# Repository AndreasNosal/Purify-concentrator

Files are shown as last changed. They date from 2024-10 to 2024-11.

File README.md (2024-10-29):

# Purify-concentrator
This device is designed to monitor and detect air quality at regular intervals, providing alerts when pollution levels become too high—prompting you to take action, such as opening a window. Ideal for indoor environments like homes, schools, or offices, it operates efficiently with a solar power input ranging from 5 to 16V.

Originally designed for: Young Energy Europe AHK Slowakei 
Link: https://slowakei.ahk.de/de

# License
 - Under GPL-3.0 license

# Use in action


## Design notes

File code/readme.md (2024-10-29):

# Starter-Friendly Electrical Project for DIY Assembly

### Contributors: 
- **Filip Greguš**
- **Andreas Nosál**

### Project:
- **Commissioned by**: Young Energy Europe AHK Slowakei
- **Date**: 29 October 2024
- **License**: [GNU General Public License v3.0](https://www.gnu.org/licenses/gpl-3.0.html)
- **Programming language**: micropython
- **Microcontroller**: ESP32 Wemos D1 mini - WROOM-32

## Hardware Components

1. **ESP32 microcontroller**: Main control unit for executing code and handling inputs/outputs.
2. **BME680 Sensor**: Measures temperature, pressure, humidity, and gas levels.
3. **SSD1306 OLED Display**: Displays real-time data.
4. **Battery and Power Monitoring**: Tracks battery voltage and alerts on low charge.
5. **LEDs and Buzzer**: Provides visual and audio notifications based on sensor data.

---

## Code Explanation and Main Functionalities

- **Sensor Initialization**: Initializes the I2C connection with the BME680 sensor and OLED display.
- **Environmental Data Processing**: Reads temperature, pressure, humidity, and gas data from the sensor and calculates an Indoor Air Quality (IAQ) index.
- **Battery Monitoring**: Reads and computes the battery percentage based on ADC voltage input.
- **LED & Buzzer Notifications**: LED colors indicate air quality levels, while the buzzer sounds when IAQ exceeds safe thresholds.
- **Display Control**: Cycles through different display modes showing temperature, humidity, pressure, and battery status.
- **Data Storage**: Saves IAQ, gas levels, uptime, and other data to RTC memory for persistence after restarts.
- **Data Persistence**: Saves readings to RTC memory for recovery after power loss or restart.
- **Deep Sleep Mode**: Activates deep sleep during idle times to conserve battery.

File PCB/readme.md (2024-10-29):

# Starter-Friendly Electrical Design for DIY Assembly

This project is an electrical design crafted to be accessible for **beginners**. It employs **through-hole components (THD)**, making it easy to assemble with a standard soldering iron. All complex circuitry is integrated into modules that mount directly onto the main PCB, eliminating the need for surface-mount devices (SMD) and simplifying the soldering process.

## Features

- **Overvoltage Protection**: Prevents damage from voltage spikes.
- **Reverse Voltage Protection**: Guards against incorrect polarity connections.
- **Active Buzzer & LED Indicators**: Provides clear audio and visual feedback.
- **Energy-Efficient Components**: Designed to conserve power.
- **Flexible Input Voltage (5-16V)**: Compatible with a range of sources, including solar panels.
- **Microcontroller Reset Button**: Convenient reset for the ESP32 microcontroller.
- **Input Power Options**: Supports both DC barrel jack and PH2 connectors.

## PCB Specifications

- **4-Layer PCB**
- **Dimensions**: 100x100 mm
- **Manufacturing**: Gerber files are available in the `gerber` directory, ready for JLCPCB.

[yee_diagram.pdf](https://github.com/user-attachments/files/17554162/yee_diagram.pdf)


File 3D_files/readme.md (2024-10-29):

# Device Case Instructions

This device case is designed for **standard 3D printers** (FFF/FDM) such as the Prusa MK3S and Ender 3.

### Printing Recommendations
- **Supports**: Minimal supports required.
- **Material**: PLA recommended (eco-friendly, organic plastic).

### Features
- **Protection**: Shields internal components with a professional, sleek design.
- **Indoor Use**: Ideal for home, work, or school environments. **Not recommended** for outdoor use.

### Solar Panel Stands
- **Tool-Free Installation**: Stands for solar panels can be easily inserted or removed without any tools.

### Assembly
To tighten and reinforce the case, you’ll need:
- **4 M3 screws (10mm length)**.

focus_maintainer
a5b3d7db-29c4-4471-a50c-b73762182b38

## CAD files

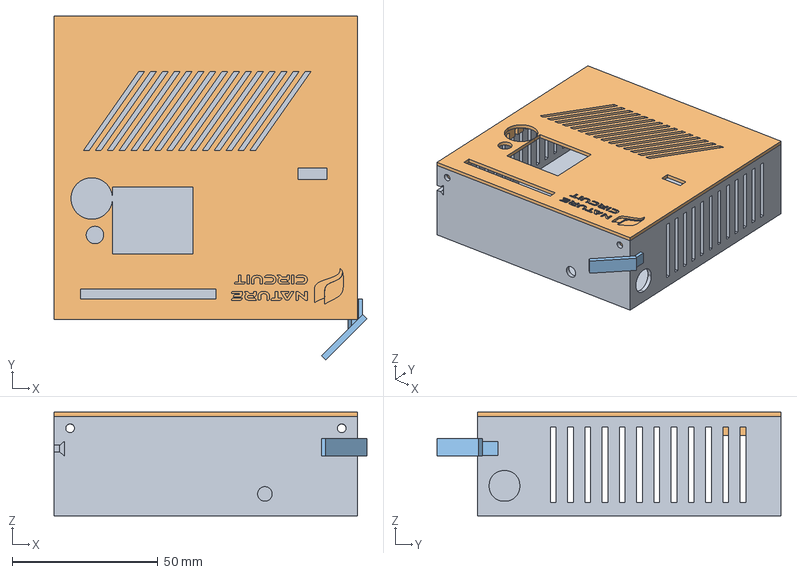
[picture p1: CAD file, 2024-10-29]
3D_files/Focus maintainer v24.step
107.2 x 117.8 x 35.5 mm

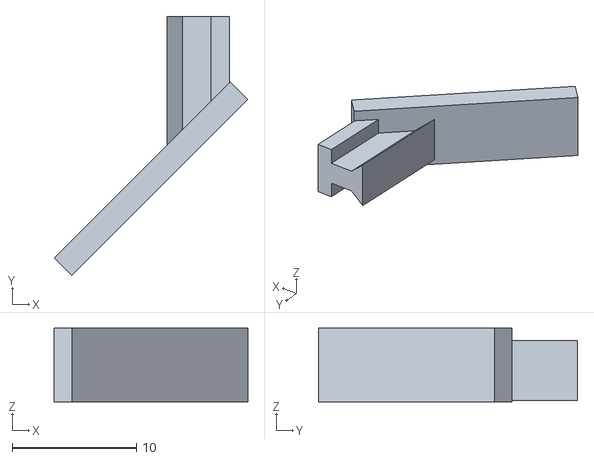
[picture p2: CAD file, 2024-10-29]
3D_files/solar_holder.stl
15.6 x 20.8 x 5.93

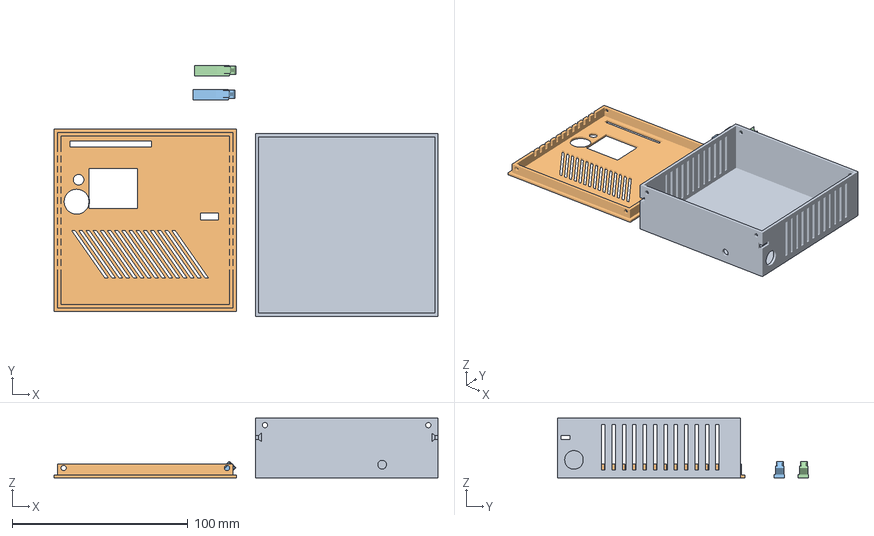
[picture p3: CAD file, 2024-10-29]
3D_files/YEE.3mf
218.6 x 142.7 x 34.0 mm
bottom_box.stl
top_box.stl
solar_holder.stl

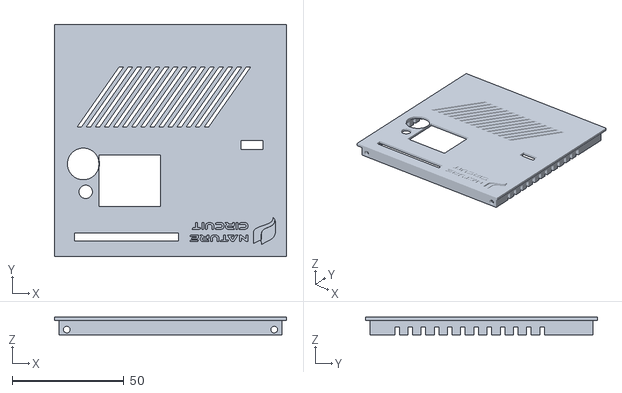
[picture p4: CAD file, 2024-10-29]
3D_files/top_box.stl
104.0 x 104.0 x 8.00

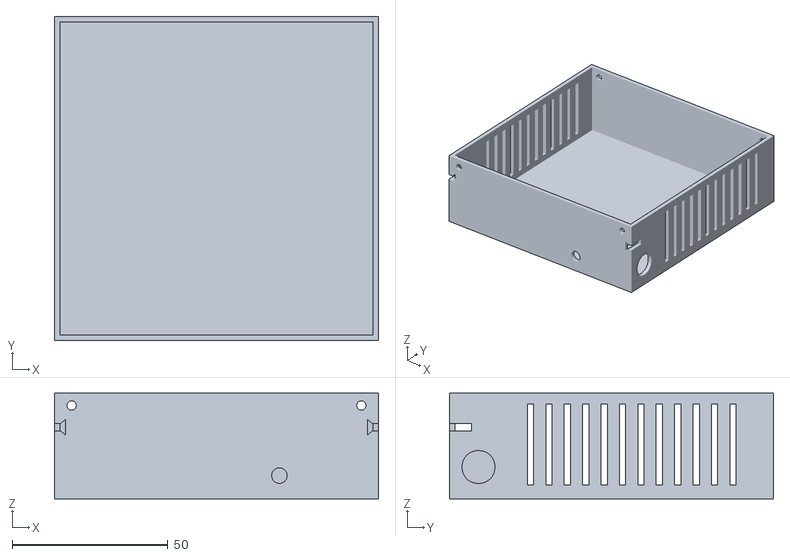
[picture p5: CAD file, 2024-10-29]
3D_files/bottom_box.stl
104.0 x 104.0 x 34.0

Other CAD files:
3D_files/Focus maintainer v24.f3d

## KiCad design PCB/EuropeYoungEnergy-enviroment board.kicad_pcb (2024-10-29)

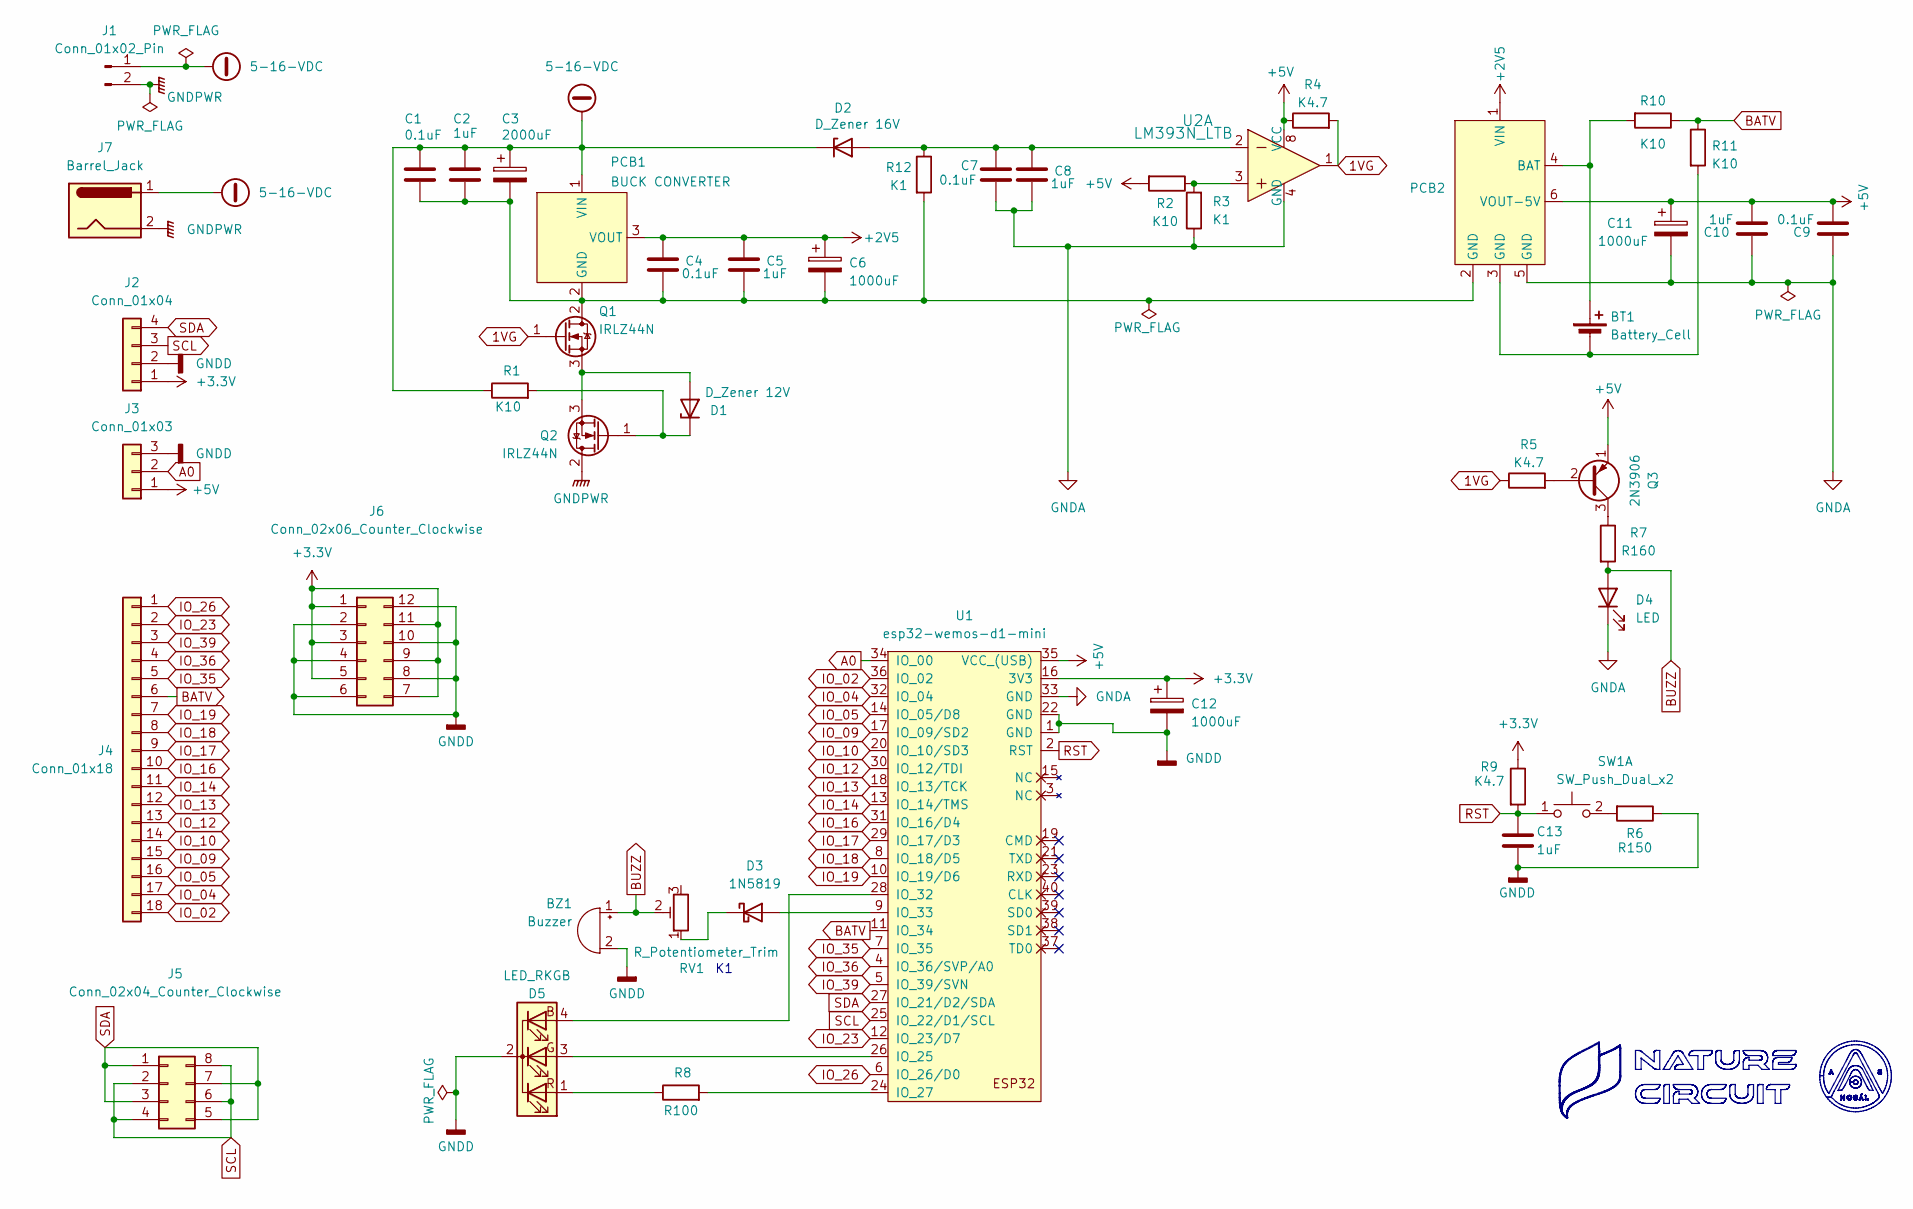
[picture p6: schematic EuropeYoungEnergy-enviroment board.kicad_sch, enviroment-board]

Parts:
BT1: Battery_Cell; BatteryHolder_MPD_BH-18650-PC2
BZ1: Buzzer; Buzzer_12x9.5RM7.6
C1, C4, C7, C9: 0.1uF; C_Disc_D4.3mm_W1.9mm_P5.00mm
C2, C5, C8, C10, C13: 1uF; C_Disc_D4.3mm_W1.9mm_P5.00mm
C3: 2000uF; CP_Radial_D12.5mm_P5.00mm
C6, C11, C12: 1000uF; CP_Radial_D12.5mm_P5.00mm
D1: D_Zener 12V; D_A-405_P10.16mm_Horizontal
D2: D_Zener 16V; D_A-405_P7.62mm_Horizontal
D3: 1N5819; D_A-405_P7.62mm_Horizontal
D4: LED; LED_D5.0mm
D5: LED_RKGB; RGB_LED
J1: Conn_01x02_Pin; JST_PH_B2B-PH-K_1x02_P2.00mm_Vertical
J2: Conn_01x04; PinHeader_1x04_P2.54mm_Vertical
J3: Conn_01x03; PinHeader_1x03_P2.54mm_Vertical
J4: Conn_01x18; PinHeader_1x18_P2.54mm_Vertical
J5: Conn_02x04_Counter_Clockwise; PinHeader_2x04_P2.54mm_Vertical
J6: Conn_02x06_Counter_Clockwise; PinHeader_2x06_P2.54mm_Vertical
J7: Barrel_Jack; Barrel_Jack_5.5mmODx2.1mmID_PJ-202A
PCB1: BUCK CONVERTER; TZT_4A_Mini_DC_DC_Buck_Converter
PCB2: MH_CD42_Charge_Discharge_Module
Q1, Q2: IRLZ44N; TO-220-3_Vertical
Q3: 2N3906; TO-92_Inline
R1, R2, R10, R11: K10; R_Axial_DIN0207_L6.3mm_D2.5mm_P10.16mm_Horizontal
R3, R12: K1; R_Axial_DIN0207_L6.3mm_D2.5mm_P10.16mm_Horizontal
R4, R5, R9: K4.7; R_Axial_DIN0207_L6.3mm_D2.5mm_P10.16mm_Horizontal
R6: R150; R_Axial_DIN0207_L6.3mm_D2.5mm_P10.16mm_Horizontal
R7: R160; R_Axial_DIN0207_L6.3mm_D2.5mm_P10.16mm_Horizontal
R8: R100; R_Axial_DIN0207_L6.3mm_D2.5mm_P10.16mm_Horizontal
RV1: R_Potentiometer_Trim; Potentiometer_Bourns_3296W_Vertical
SW1: SW_Push_Dual_x2; SW_SPST_Omron_B3F-40xx
U1: esp32-wemos-d1-mini
U2: LM393N_LTB; DIP-8_W7.62mm; MPN LM393N; Digi-Key_PN LM393NFS-ND

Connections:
1VG: Q1.1 (G), R4.2, R5.1, U2.1
5-16-VDC: C1.1, C2.1, C3.1, D2.1 (K), J1.1, J7.1, PCB1.1 (VIN), R1.1
+2V5: C4.1, C5.1, C6.1, PCB1.3 (VOUT), PCB2.1 (VIN)
+3.3V: C12.1, J2.1, J6.1, J6.3, J6.5, J6.7, J6.9, J6.11, R9.1, U1.16 (3V3)
+5V: C9.2, C10.2, C11.1, J3.1, PCB2.6 (VOUT-5V), Q3.1 (E), R2.2, R4.1, U1.35 (VCC_(USB)), U2.8 (VCC)
A0: J3.2, U1.34 (IO_00)
BATV: J4.6, R10.1, R11.1, U1.11 (IO_34)
BUZZ: BZ1.1 (+), D4.2 (A), R7.2, RV1.2
GNDA: C7.2, C8.2, C9.1, C10.1, C11.2, D4.1 (K), PCB2.5 (GND), R3.1, U1.33 (GND), U2.4 (GND)
GNDD: BZ1.2 (-), C12.2, C13.2, D5.2 (K), J2.2, J3.3, J6.2, J6.4, J6.6, J6.8, J6.10, J6.12, R6.1, U1.1 (GND), U1.22 (GND)
GNDPWR: J1.2, J7.2, Q2.2 (D)
IO_02: J4.18, U1.36 (IO_02)
IO_04: J4.17, U1.32 (IO_04)
IO_05: J4.16, U1.14 (IO_05/D8)
IO_09: J4.15, U1.17 (IO_09/SD2)
IO_10: J4.14, U1.20 (IO_10/SD3)
IO_12: J4.13, U1.30 (IO_12/TDI)
IO_13: J4.12, U1.18 (IO_13/TCK)
IO_14: J4.11, U1.13 (IO_14/TMS)
IO_16: J4.10, U1.31 (IO_16/D4)
IO_17: J4.9, U1.29 (IO_17/D3)
IO_18: J4.8, U1.8 (IO_18/D5)
IO_19: J4.7, U1.10 (IO_19/D6)
IO_23: J4.2, U1.12 (IO_23/D7)
IO_26: J4.1, U1.6 (IO_26/D0)
IO_35: J4.5, U1.7 (IO_35)
IO_36: J4.4, U1.4 (IO_36/SVP/A0)
IO_39: J4.3, U1.5 (IO_39/SVN)
unnamed: BT1.1 (+), PCB2.4 (BAT), R10.2
unnamed: BT1.2 (-), PCB2.3 (GND), R11.2
unnamed: D1.2 (A), Q1.3 (S), Q2.3 (S)
unnamed: D1.1 (K), Q2.1 (G), R1.2
unnamed: C7.1, C8.1, D2.2 (A), R12.1, U2.2
unnamed: D3.2 (A), U1.9 (IO_33)
unnamed: D3.1 (K), RV1.1
unnamed: D5.4 (BA), U1.28 (IO_32)
unnamed: D5.3 (GA), U1.26 (IO_25)
unnamed: D5.1 (RA), R8.1
unnamed: C1.2, C2.2, C3.2, C4.2, C5.2, C6.2, PCB1.2 (GND), PCB2.2 (GND), Q1.2 (D), R12.2
unnamed: Q3.2 (B), R5.2
unnamed: Q3.3 (C), R7.1
unnamed: R2.1, R3.2, U2.3
unnamed: R6.2, SW1.2 (D)
unnamed: R8.2, U1.24 (IO_27)
RST: C13.1, R9.2, SW1.1 (C), U1.2 (RST)
SCL: J2.3, J5.2, J5.4, J5.6, J5.8, U1.25 (IO_22/D1/SCL)
SDA: J2.4, J5.1, J5.3, J5.5, J5.7, U1.27 (IO_21/D2/SDA)

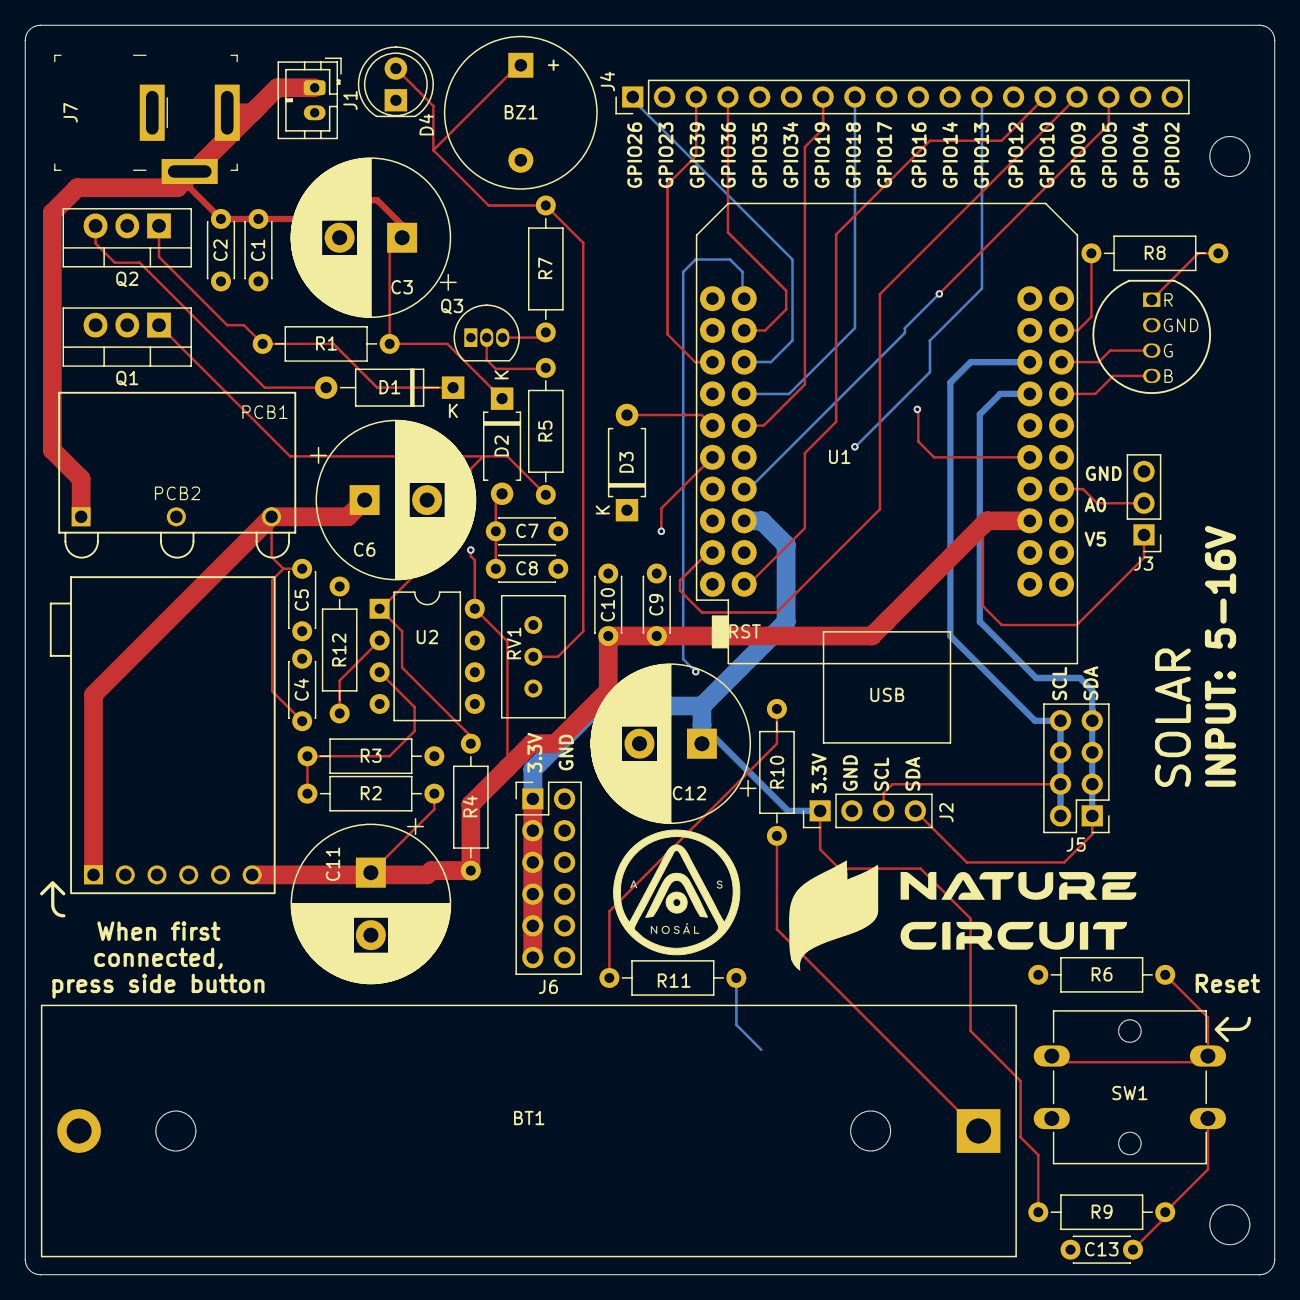
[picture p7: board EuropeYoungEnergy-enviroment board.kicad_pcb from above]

Board: 4 copper layers, 100.0 x 100.0 mm, 48 parts (0 on the bottom side), 47 nets.

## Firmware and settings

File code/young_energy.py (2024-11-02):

#
# This code was made by: Filip Greguš, Andreas Nosál
#
# Project for: Young Energy Europe AHK Slowakei
# Date: 2 november 2024
#
# This code is under: The GNU General Public License v3.0

from machine import Pin, I2C, Timer, PWM, ADC, deepsleep, freq, RTC
import ssd1306, esp32
from bme680 import *
from time import time, ticks_diff, ticks_ms, sleep_ms
import sys
import esp32


i2c_ok = False

i2c = I2C(0, scl=Pin(22), sda=Pin(21))
try:
    bme = BME680_I2C(i2c)
    display = ssd1306.SSD1306_I2C(64, 48, i2c)
    i2c_ok = True
except:
    i2c_ok = False


red_led = PWM(Pin(27), freq=2000, duty_u16=0)
green_led = PWM(Pin(25), freq=2000, duty_u16=0)
blue_led = PWM(Pin(32), freq=2000, duty_u16=0)

buzzer = PWM(Pin(33))
buzzer.deinit()

adc = ADC(Pin(34))
adc.atten(ADC.ATTN_11DB)
adc.width(ADC.WIDTH_12BIT)

displayOn = False
displayState = 1
displayChanged = False
timerStarted = False
measureCount = -1

def move(pin):
    sleep_ms(10)
    if not pin.value(): return
    
    global displayOn
    displayOn = True

pir = Pin(0, Pin.IN)
pir.irq(handler = move, trigger = Pin.IRQ_RISING)
move(pir)

# Lithium battery voltage parameters
MAX_BATTERY_VOLTAGE = 4.1
MIN_BATTERY_VOLTAGE = 3.15
VOLTAGE_DIVIDER_RATIO = 2

freq(80000000);

rtc = RTC()


def offLed():
    global red_led, green_led, blue_led
    red_led.duty_u16(0)
    green_led.duty_u16(0)
    blue_led.duty_u16(0)


def save_to_nvs(measureCount, min_gas, max_gas, timestamp, uptime_run, gas, iaq):
    rtc.memory(f"{measureCount},{min_gas},{max_gas},{timestamp},{uptime_run},{gas},{iaq}")


def load_from_nvs():
    data = rtc.memory()
    print(data)
    if data:
        try:
            measureCount, min_gas, max_gas, timestamp, uptime_run, gas, iaq = map(int, data.decode().split(','))
            return measureCount, min_gas, max_gas, timestamp, uptime_run, gas, iaq
        except:
            return -1, 1_000_000_000, 0, 0, 0, 0, 0  # Default values if parsing fails
    return -1, 1_000_000_000, 0, 0, 0, 0, 0  # Default values if no data found


def read_adc(adc, count=50):
    values = []
    for i in range(count):
        values.append(adc.read_uv())
    
    average = sum(values) / count / 1_000_000

    values.sort()
    median = values[count // 2] / 1_000_000
    
    third_count = count // 3
    average_middle = sum(values[third_count : 2*third_count]) / third_count / 1_000_000
    
    return (average, average_middle, median)

def get_battery_percentage(voltage):
    voltage *= VOLTAGE_DIVIDER_RATIO
    if voltage > MAX_BATTERY_VOLTAGE:
        return 100
    elif voltage < MIN_BATTERY_VOLTAGE:
        return 0
    else:
        return int(((voltage - MIN_BATTERY_VOLTAGE) / (MAX_BATTERY_VOLTAGE - MIN_BATTERY_VOLTAGE)) * 100)

def warning():
    global red_led, buzzer    
    buzzer.init(freq = 2000, duty_u16 = 0)
    offLed()
    
    for duty in (2**15, 0, 2**15, 0):
        red_led.duty_u16(duty)
        buzzer.duty_u16(duty)
        sleep_ms(1000)
    
    if measureCount > 5:
        indicateOnLed(iaq)
        
def getTimeSeconds(rtc):
    current_timestamp = rtc.datetime()
    seconds = current_timestamp[6] + (current_timestamp[5] * 60 + current_timestamp[4] *3600)
    return seconds

if not i2c_ok:
    warning()
    sys.exit()

gas = 0
iaq = 0
min_gas = 1_000_000_000
max_gas = 0

measureCount, min_gas, max_gas, last_logged_time, uptime_run, gas, iaq = load_from_nvs()

uptime_run += getTimeSeconds(rtc) - uptime_run

if not displayOn and uptime_run < 120:
    deepsleep(2500)

if get_battery_percentage(battery_voltage) == 0:
    deepsleep(60000)
    

temperature = bme.temperature
pressure = bme.pressure
humidity = bme.humidity
gas = gas / 100
iaq = iaq / 100

if (getTimeSeconds(rtc) - last_logged_time) > 120:
    measureCount = -1
    min_gas = 1_000_000_000  # Reset the gas calibration values
    max_gas = 0
    uptime_run = 0


def normalize_with_midpoint(value, min_val, mid_val, max_val):
    if value < mid_val:
        norm_value = (value - mid_val) / (mid_val - min_val)
    else:
        norm_value = (value - mid_val) / (max_val - mid_val)
    
    return max(-1, min(norm_value, 1))  # Orezanie do rozsahu -1 až 1


def calculate_iaq(gas, humidity, temperature):    
    norm_humidity = normalize_with_midpoint(humidity, 30, 45, 60)  # Optimálna vlhkosť 45%
    norm_temperature = normalize_with_midpoint(temperature, 18, 23, 28)  # Optimálna teplota 23°C
    
    abs_humidity = abs(norm_humidity)
    abs_temperature = abs(norm_temperature)
    
    iaq = (0.5 * gas) + (0.25 * abs_humidity) + (0.25 * abs_temperature)
    iaq_index = iaq * 500  # Škálovanie na rozsah 0 - 500
    
    return iaq_index

def gasAlogorithm():
    global bme, temperature, pressure, humidity, gas, iaq
    global measureCount, min_gas, max_gas

    temperature = bme.temperature
    measured_gas = bme.gas
    pressure = bme.pressure
    humidity = bme.humidity
    
    print("nameralo sa", measured_gas)

    measureCount += 1

    # Update the min/max gas values
    if measureCount > 3:
        if measured_gas > max_gas:
            max_gas = measured_gas
        elif measured_gas < min_gas:
            min_gas = measured_gas
        gas = ((measured_gas - min_gas) / (max_gas - min_gas))

    # Calculate IAQ if enough measurements have been taken
    if measureCount > 5:
        iaq = calculate_iaq(1 - gas, humidity, temperature)


def indicateOnLed(iaq):    
    global red_led, green_led, blue_led
    offLed()
    
    if iaq < 100:
        green_led.duty_u16(2**14)
    elif iaq < 200:
        red_led.duty_u16(2**15)
        green_led.duty_u16(2**12)
    elif iaq < 300:
        red_led.duty_u16(2**15)
        green_led.duty_u16(2**8)
    else:
        red_led.duty_u16(2**15)          

    
def changeDisplayMode(t):
    
    global displayState, displayChanged, measureCount
    
    if displayState < 5:
        displayState += 1
        displayChanged = True
    else:
        offLed()
        displayState = 1
        shutDownDisplay()
    
        
def printOnDisplay():
    global displayState, display
    global temperature, pressure, humidity, gas
    
    display.fill(0)
    if displayState == 1:
        display.text("Teplota", 0, 0, 1)
        display.text("{:.2f}".format(temperature)+"'C", 0, 25, 1)
        display.show()
        
    elif displayState == 2:
        display.text("Vlchkost", 0, 0, 1)
        display.text("{:.2f}".format(humidity)+"%", 0, 25, 1)
        display.show()
        
    elif displayState == 3:
        display.text("Tlak", 0, 0, 1)
        display.text("{:.0f}".format(pressure)+"hPa", 0, 25, 1)
        display.show()
        
    elif displayState == 4:
        battery_voltage = read_adc(adc)[1]
        battery_percentage = get_battery_percentage(battery_voltage)
        display.text("Baterka", 0, 0, 1)
        display.text(f"{battery_percentage}%", 0, 25, 1)
        display.show()

        # Battery low warning
        if battery_percentage <= 10:
            display.text("Pozor", 0, 40, 1)
            display.show()
            warning()
            
    elif displayState == 5:
        if measureCount < 5:
            display.text("Prebieha", 0, 0, 1)
            display.text("priprava", 0, 20, 1)
            display.text(f"{round(150 - uptime_run - (measureCount * 30))}s", 0, 40, 1)
            display.show()
        else:
            display.text("VOC", 0, 0, 1)
            display.text("{:.2f}".format(100 *(iaq / 500))+"%", 0, 25, 1)
            display.text("{:.2f}".format(round(iaq))+"ppm", 0, 40, 1)
            display.show()
        

def shutDownDisplay():
    global displayOn, timerStarted, timer, display
    displayOn = False
    timerStarted = False
    timer.deinit()
    display.poweroff()    


timer = Timer(-1)

while True:
    start = getTimeSeconds(rtc)
    
    if uptime_run >= 120:
        uptime_run = uptime_run % 120
        startTick = ticks_ms()
        gasAlogorithm()  
            
    if displayOn:
        if not timerStarted:           
            if measureCount > 5:
                if measureCount > 15 and iaq > 400:
                    warning()
                indicateOnLed(iaq)
            display.poweron()
            timer.init(callback = changeDisplayMode, period = 5000)
            timerStarted = True
            displayChanged = True
            
        if displayChanged:            
            printOnDisplay()
            displayChanged = False
        
    if not timerStarted:
        uptime_run += getTimeSeconds(rtc) - start
        
        save_to_nvs(measureCount, min_gas, max_gas, getTimeSeconds(rtc), uptime_run +
                    (start - last_logged_time), int(gas * 100), int(iaq * 100))
        deepsleep(2500)

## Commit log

2024-10-24 add code for device
2024-10-29 Added kicad files - version 8.0
    [EuropeYoungEnergy-enviroment board.kicad_pcb, EuropeYoungEnergy-enviroment board.kicad_sch]
2024-10-29 Added zip gerber
    Files for JLCPCB manufacturing
2024-10-29 Added 3D files
    [Focus maintainer v24.f3d, Focus maintainer v24.step, YEE.3mf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]
2024-10-29 Update readme.md for circuitry
2024-11-02 added bigger interval for BME680, changed battery minimum votlage
    interval for BME680 changed from 30 seconds to 120 seconds.
    Minimum battery voltage to 3.15. Even if it's not the minimum voltage for lithium battery, the charging circuit is set to that minimum. After this minimum is passed, the microcontroller deepsleeps fo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
